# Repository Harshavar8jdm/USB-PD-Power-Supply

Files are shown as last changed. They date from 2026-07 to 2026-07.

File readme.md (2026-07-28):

# CH224A USB Power Delivery (PD) Trigger Board

A 4-layer custom printed circuit board designed around the WCH CH224A USB Power Delivery sink controller. This board requests discrete voltage profiles from 5V up to 28V (USB PD 3.0 / 3.1 EPR) at power levels up to 100W, making standard USB-C PD power supplies usable for bench instruments, prototypes, and DC-powered devices.

---

## Board Visuals

### 3D Renders
| Top View | Bottom View |
| :---: | :---: |
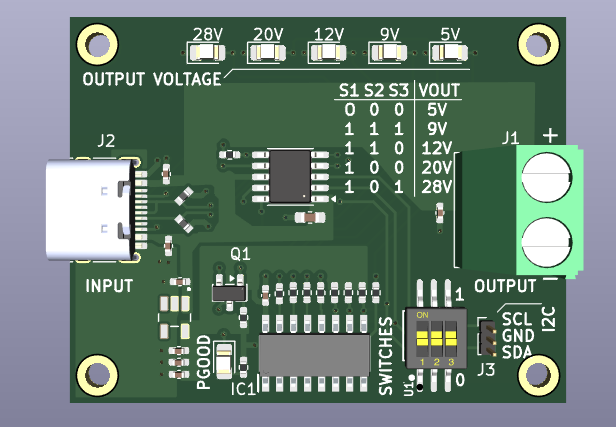
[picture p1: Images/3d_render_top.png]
3D Render Top
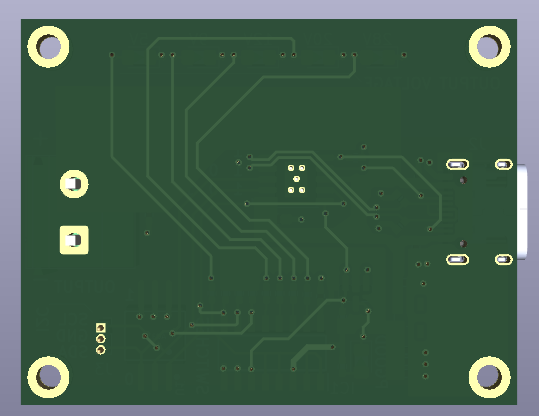
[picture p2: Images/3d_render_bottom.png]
3D Render Bottom
|  |  |

---

## Features

* **Wide Voltage Range:** Requests 5V, 9V, 12V, 20V, or 28V output based on switch configuration or digital override.
* **Dual Control Modes:** Manual hardware selection via a 3-position DIP switch, or digital register control over an onboard I2C header.
* **Visual Status Indicators:** Dedicated surface-mount LEDs for each voltage profile (5V, 9V, 12V, 20V, 28V).
* **High-Current Power Path:** Solid copper pours on VBUS and GND pads of the 16-pin USB-C receptacle to reduce resistance and thermal rise under 5A loads.
* **4-Layer PCB Layout:** Dedicated internal ground planes (Layer 2 & Layer 3) provide return paths and heat spreading.
* **Silkscreen Truth Table:** Printed reference table on top silk for direct voltage-setting configuration without consulting external documentation.
* **Output Termination:** 2-pin Phoenix screw terminal block for connection to external loads.

---

## Specifications

| Parameter | Specification |
| :--- | :--- |
| **Input Connector** | 16-Pin USB Type-C Receptacle (`J2`) |
| **Output Connector** | 2-Pin Screw Terminal Block (`J1`) |
| **Controller IC** | WCH CH224A |
| **Supported Voltages** | 5V, 9V, 12V, 20V, 28V (EPR) |
| **Maximum Current** | Up to 5A |
| **Maximum Power** | 100W |
| **Control Interface** | 3-position DIP Switch (`S1`, `S2`, `S3`) & 3-pin I2C Header (`J3`) |
| **Stackup** | 4-layer (Signal / GND / GND / Signal) |

---

## Voltage Selection (DIP Switch Truth Table)

The DIP switch (`S1`, `S2`, `S3`) controls the configuration pins of the CH224A. Use the following logic combinations to select the target output voltage:

| S1 | S2 | S3 | Selected Output Voltage (VOUT) |
| :---: | :---: | :---: | :---: |
| `0` | `0` | `0` | **5V** |
| `1` | `1` | `1` | **9V** |
| `1` | `1` | `0` | **12V** |
| `1` | `0` | `0` | **20V** |
| `1` | `0` | `1` | **28V** |

> **Note:** The truth table is also silkscreened on the top layer of the PCB for quick reference.

---

## PCB Layout & Schematic

### Schematic Diagram
* [View Schematic (PDF)](Images/schematic.pdf)

### Layer Stackup & Routing
| Layer | Layout Image | Description |
| :--- | :---: | :--- |
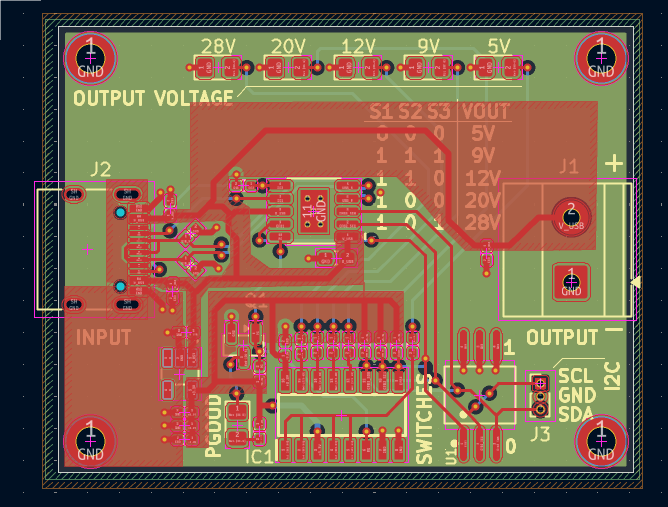
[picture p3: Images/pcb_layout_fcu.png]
Top Layer
| **Top Layer (F.Cu)** |  | Signal routing, component placement, voltage LEDs, and `V_USB` power pours. |
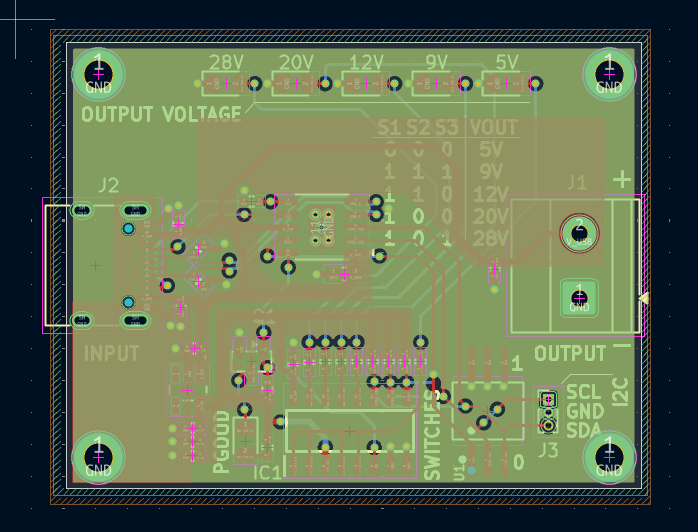
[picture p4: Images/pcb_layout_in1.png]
Inner Layer 1
| **Inner Layer 1 (In1.Cu)** |  | Continuous Ground Plane (GND). |
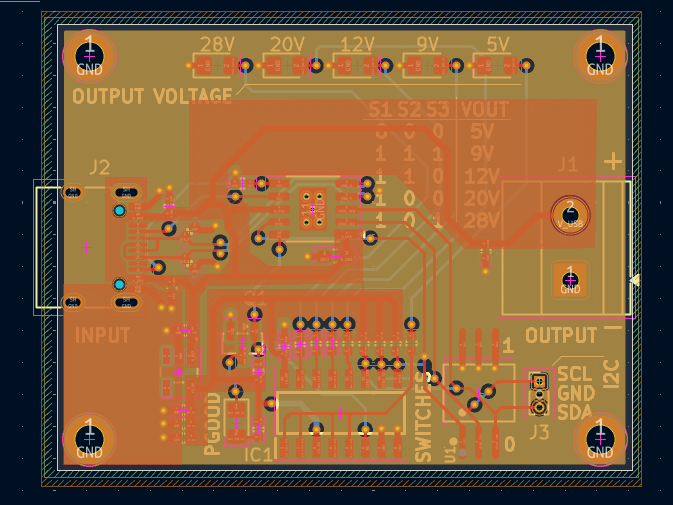
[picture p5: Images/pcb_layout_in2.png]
Inner Layer 2
| **Inner Layer 2 (In2.Cu)** |  | Continuous Ground Plane (GND). |
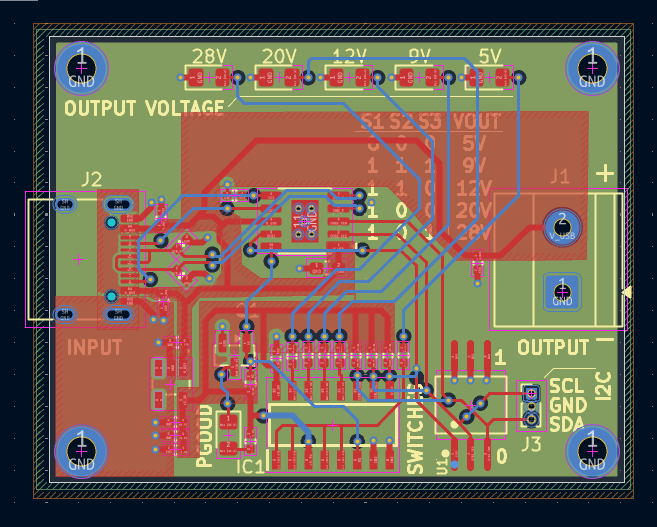
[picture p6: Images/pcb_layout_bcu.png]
Bottom Layer
| **Bottom Layer (B.Cu)** |  | Low-speed signal routing and DIP switch interconnects. |

---

## Hardware Architecture

### High-Current Design Considerations
* **Solid Copper Pours:** VBUS and GND pads on the USB-C receptacle avoid thermal relief necking to maximize current delivery up to 5A without excessive trace heating.
* **Thermal Management:** Dual internal ground planes serve as an integrated thermal heat spreader for the CH224A IC and power paths.

### Microcontroller Interface (I2C Header - J3)
The `J3` header exposes the I2C bus pins (`SCL`, `GND`, `SDA`) connected to the CH224A controller, allowing an external host MCU (e.g., STM32, ESP32, AVR) to read status registers or programmatically switch profiles.

* **Pinout:**
  1. `SCL` (I2C Clock)
  2. `GND` (Ground)
  3. `SDA` (I2C Data)
* **Bus Pull-ups:** The board omits dedicated pull-up resistors on SDA/SCL to minimize component count. Activate the internal pull-up resistors on the host microcontroller's GPIO pins when using this interface.

---

## Repository File Structure

```text
├── Images/
│   ├── 3d_render_top.png
│   ├── 3d_render_bottom.png
│   ├── pcb_layout_fcu.png
│   ├── pcb_layout_in1.png
│   ├── pcb_layout_in2.png
│   ├── pcb_layout_bcu.png
│   └── schematic.pdf
└── README.md

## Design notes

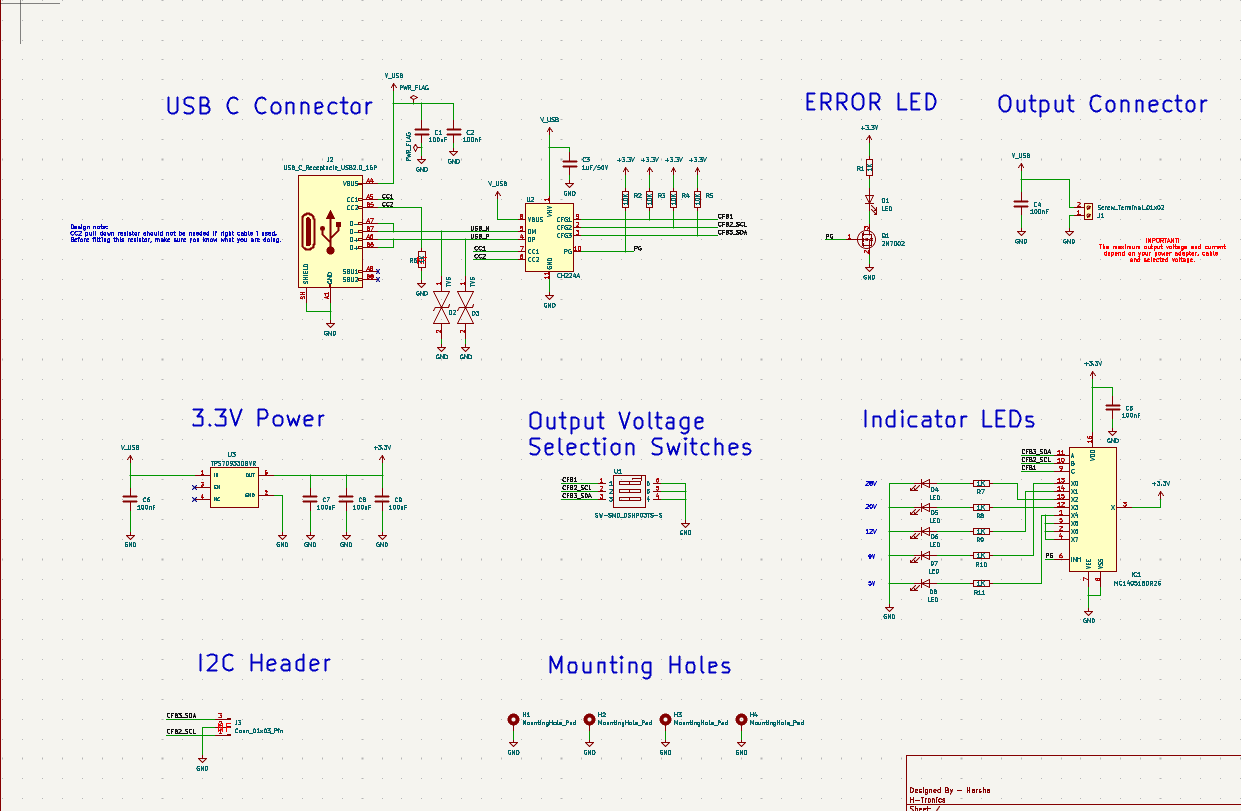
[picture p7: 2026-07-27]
Images/schematic.png

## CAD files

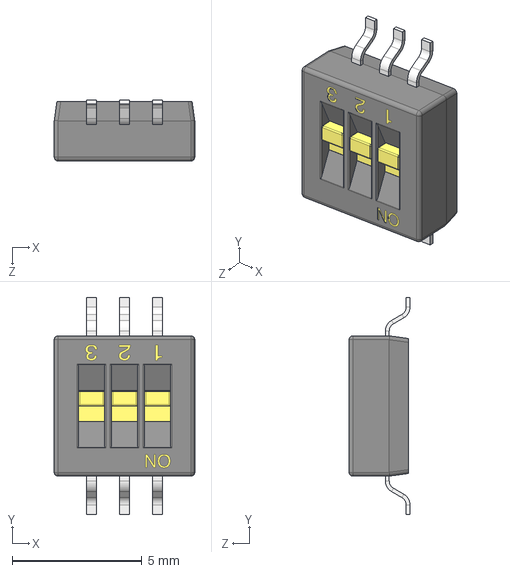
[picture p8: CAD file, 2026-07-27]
ext-libs/SW-SMD_DSHP03TS-S_DSHP03TS-S_C319051/SW-SMD_DSHP03TS-S_DSHP03TS-S_C319051.step
5.41 x 8.35 x 2.35 mm

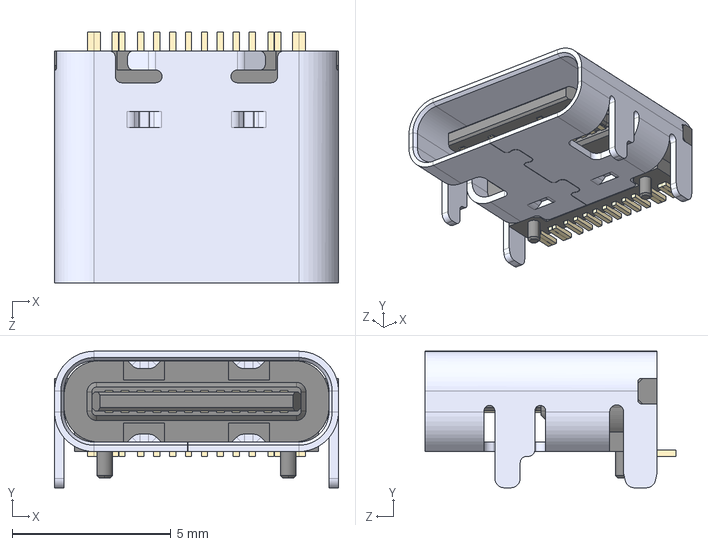
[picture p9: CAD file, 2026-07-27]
ext-libs/TYPE-C-31-M-12--3DModel-STEP-56544.STEP
8.94 x 4.30 x 7.90 mm

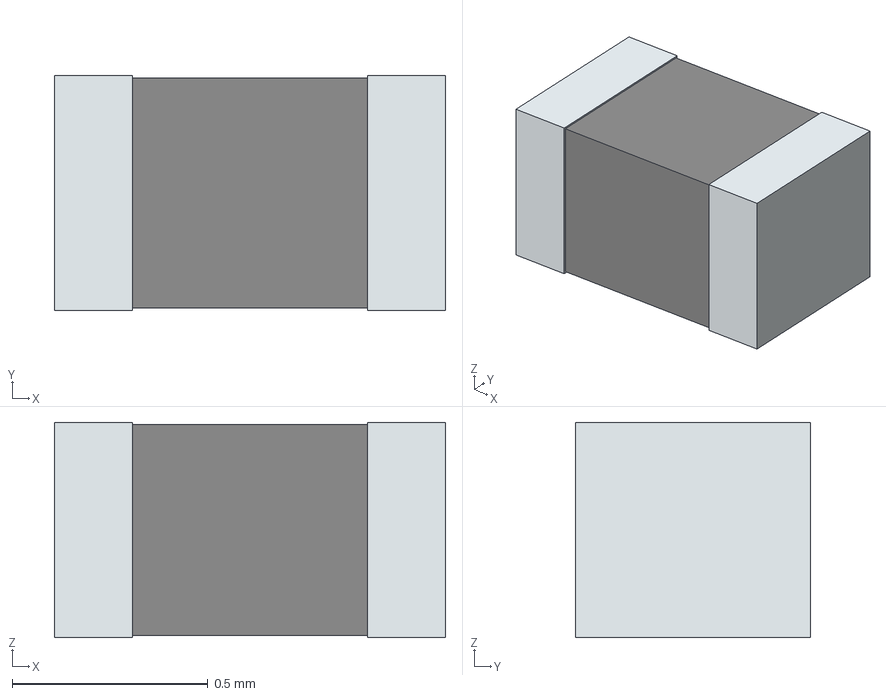
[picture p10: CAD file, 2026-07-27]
ext-libs/GG0402052R542P/3D/GG0402052R542P.stp
1.00 x 0.6 x 0.55 mm
term1
term2

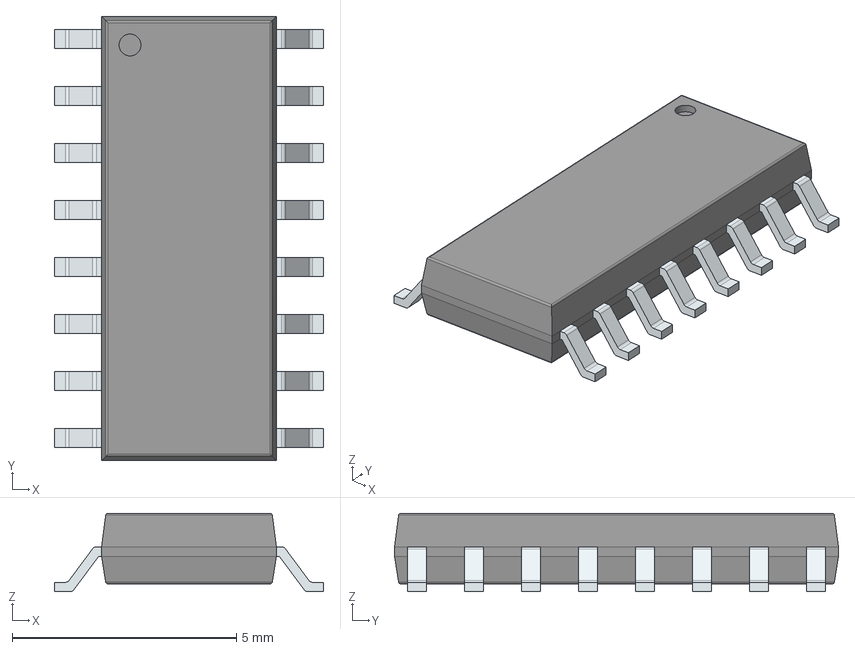
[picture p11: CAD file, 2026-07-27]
ext-libs/LIB_MC14051BDR2G/MC14051BDR2G/3D/MC14051BDR2G.stp
6.00 x 9.90 x 1.75 mm
PinsArrayLR

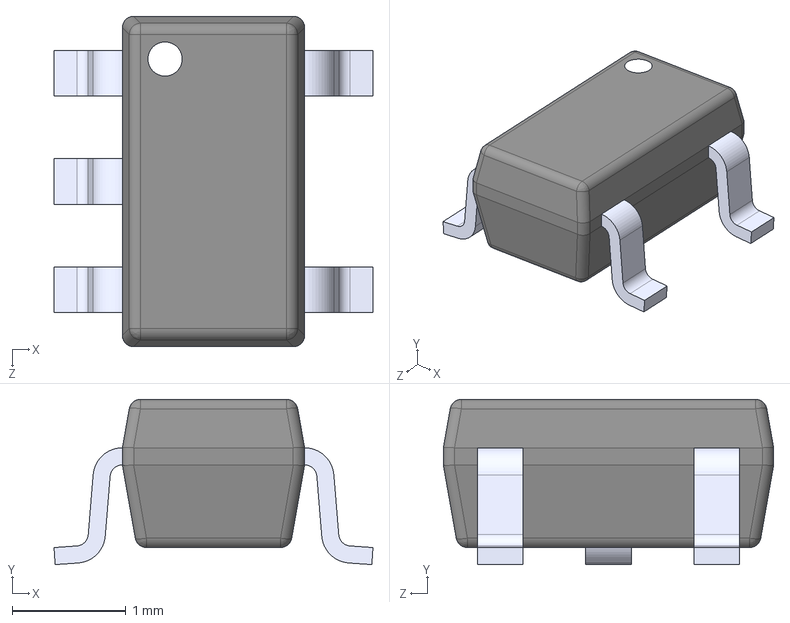
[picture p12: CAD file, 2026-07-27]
ext-libs/TPS70933DBVR/TPS70933DBVR.step
2.80 x 1.45 x 2.90 mm

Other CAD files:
ext-libs/GG0402052R542P/Allegro/dionc1006x55n.psm
ext-libs/GG0402052R542P/DEHDL/gg0402052r542p/chips/chips.prt
ext-libs/LIB_MC14051BDR2G/MC14051BDR2G/Allegro/soic127p600x175-16n.psm
ext-libs/LIB_MC14051BDR2G/MC14051BDR2G/DEHDL/mc14051bdr2g/chips/chips.prt
ext-libs/SW-SMD_DSHP03TS-S_DSHP03TS-S_C319051/SW-SMD_DSHP03TS-S_DSHP03TS-S_C319051.obj

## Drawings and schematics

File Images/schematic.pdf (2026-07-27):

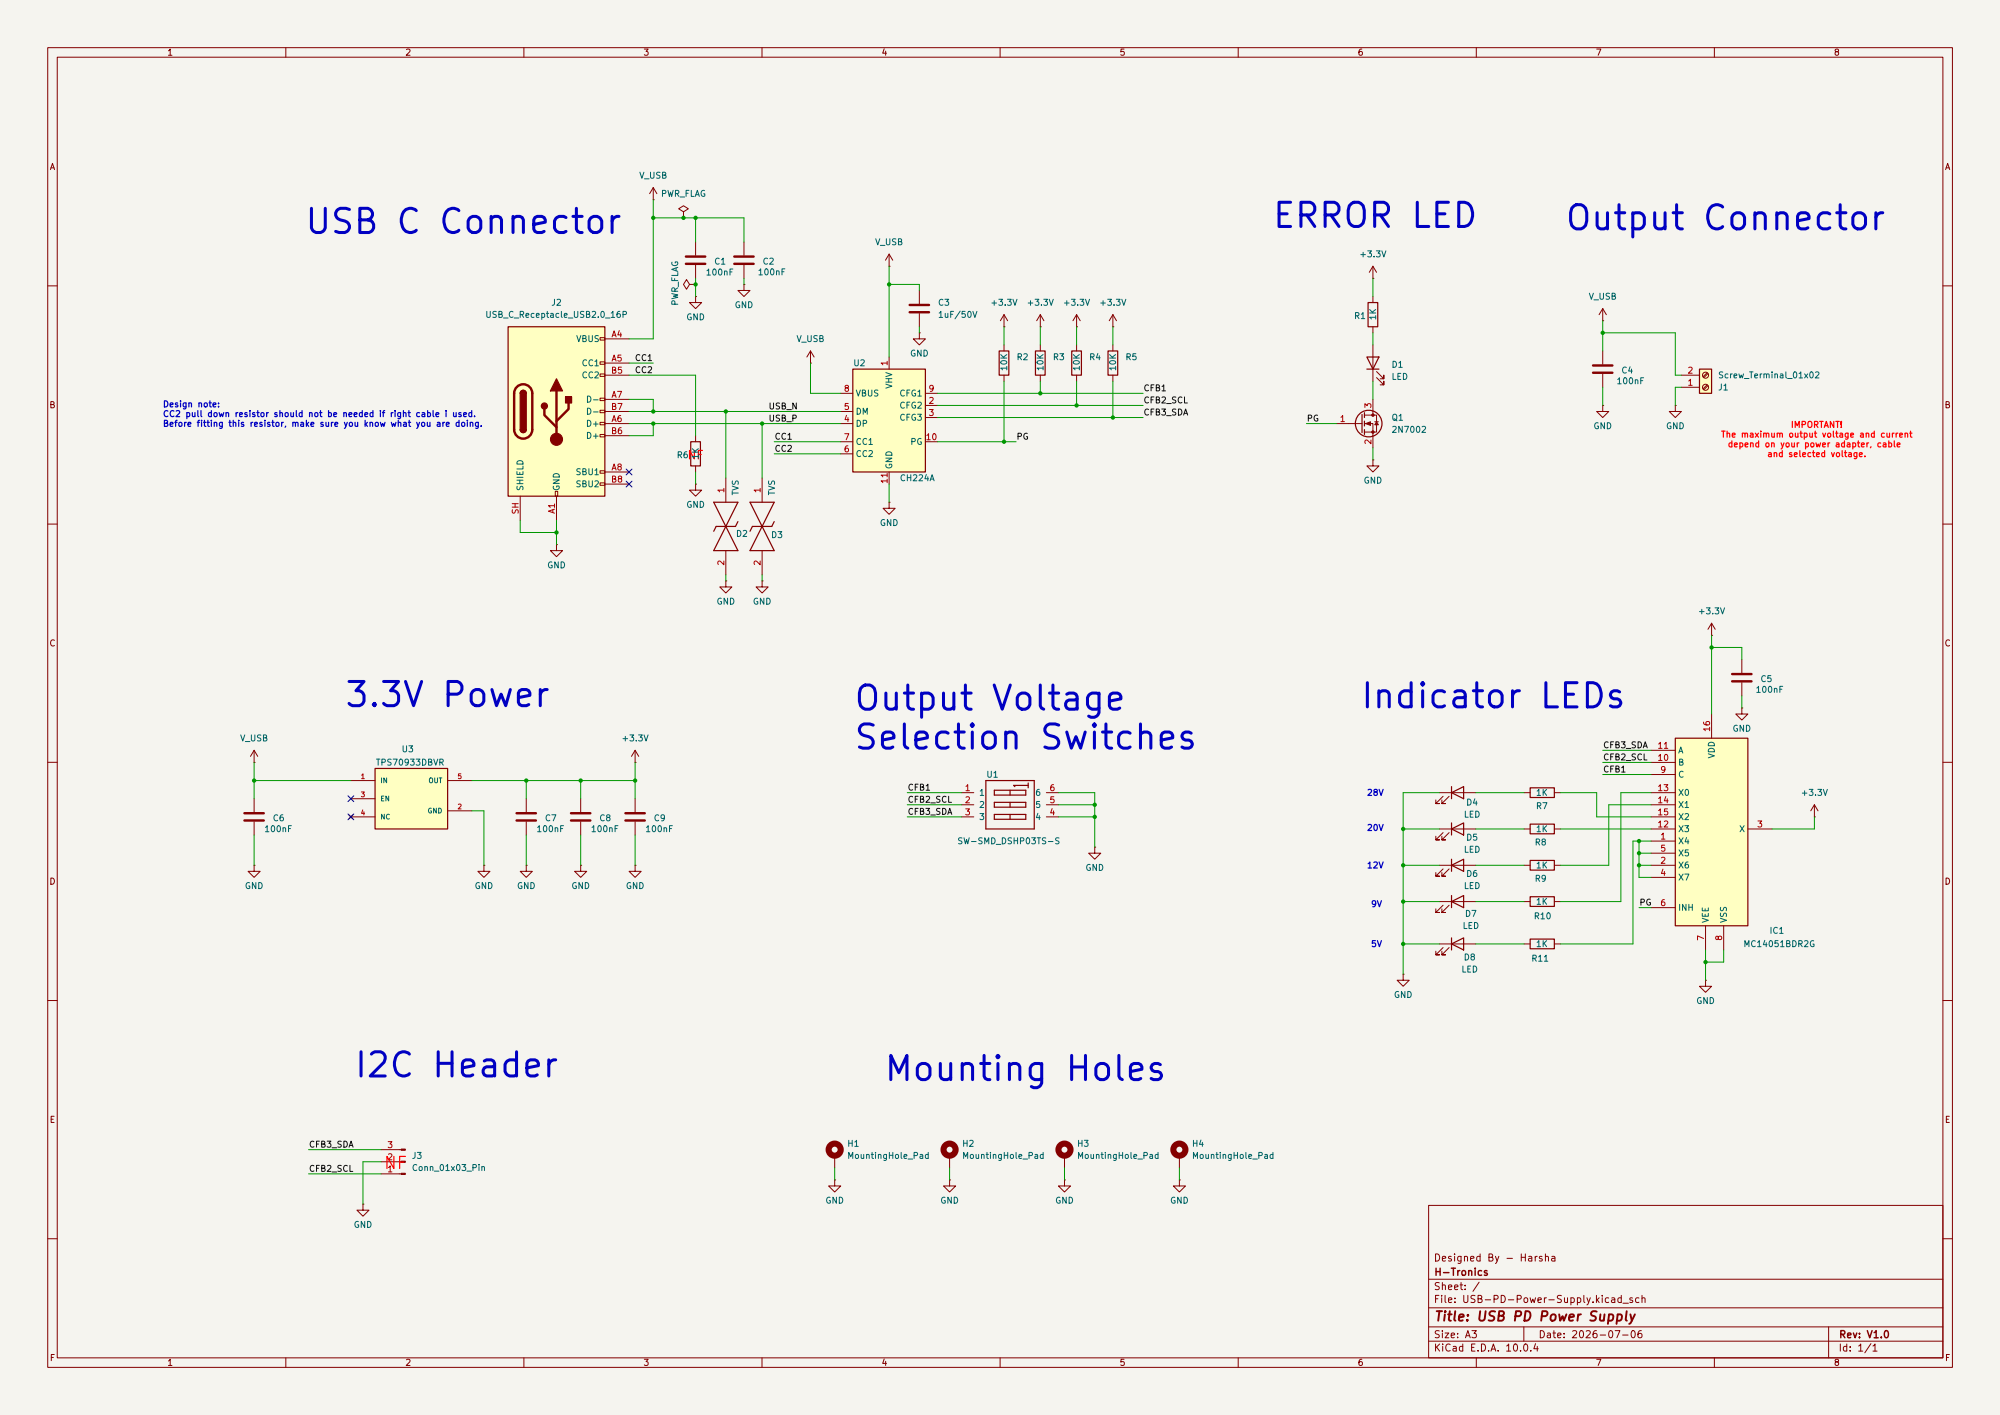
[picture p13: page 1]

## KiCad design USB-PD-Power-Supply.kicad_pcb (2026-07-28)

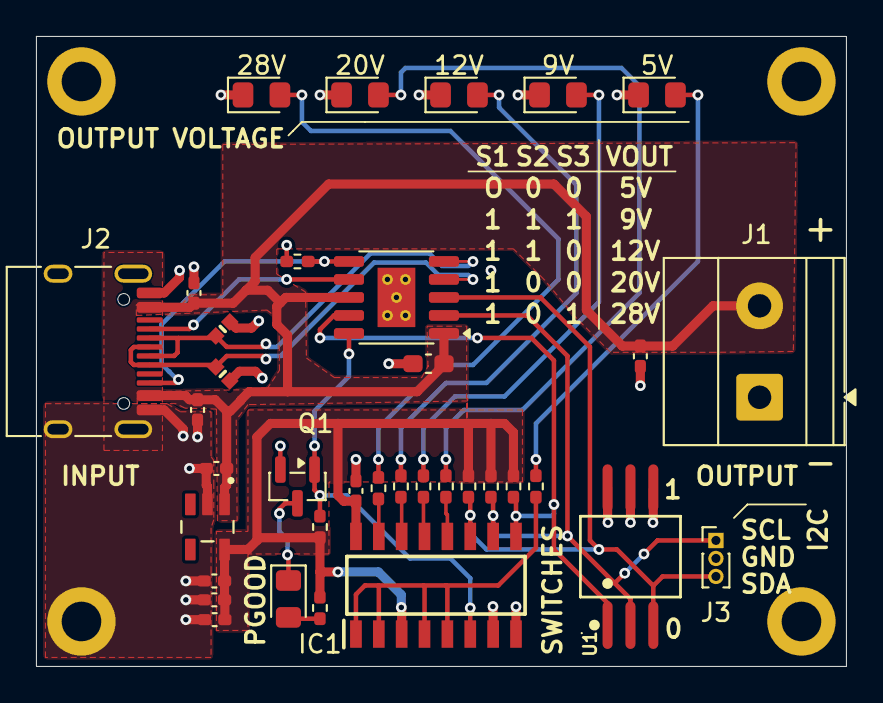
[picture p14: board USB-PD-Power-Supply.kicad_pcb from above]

Board: 4 copper layers, 45.0 x 35.0 mm, 40 parts (0 on the bottom side), 23 nets.

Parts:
5V, 9V, 12V, 20V, 28V: LED; LED_0805_2012Metric_Pad1.15x1.40mm_HandSolder
C1, C2, C4, C5, C6, C7, C8, C9: 100nF; C_0402_1005Metric_Pad0.74x0.62mm_HandSolder
C3: 1uF/50V; C_0603_1608Metric_Pad1.08x0.95mm_HandSolder
D1: LED; LED_0805_2012Metric_Pad1.15x1.40mm_HandSolder
D2, D3: TVS; DIONC1006X55N
H1, H2, H3, H4: MountingHole_Pad; MountingHole_2.2mm_M2_DIN965_Pad
IC1: MC14051BDR2G; SOIC127P600X175-16N
J1: Screw_Terminal_01x02; TerminalBlock_Phoenix_MKDS-1,5-2-5.08_1x02_P5.08mm_Horizont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
J2: USB_C_Receptacle_USB2.0_16P; USB_C_Receptacle_HRO_TYPE-C-31-M-12
J3: Conn_01x03_Pin; PinHeader_1x03_P1.00mm_Vertical
Q1: 2N7002; SOT-23
R1, R6, R7, R8, R9, R10, R11: 1K; R_0402_1005Metric_Pad0.72x0.64mm_HandSolder
R2, R3, R4, R5: 10K; R_0402_1005Metric_Pad0.72x0.64mm_HandSolder
U1: SW-SMD_DSHP03TS-S; SW-SMD_DSHP03TS-S_DSHP03TS-S_C319051
U2: CH224A; SSOP-10-1EP_3.9x4.9mm_P1mm_EP2.1x3.3mm
U3: TPS70933DBVR; SOT95P280X145-5N

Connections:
+3.3V: C5.1, C7.1, C8.1, C9.1, IC1.3 (X), IC1.16 (VDD), R1.1, R2.1, R3.1, R4.1, R5.1, U3.5 (OUT)
/CC1: J2.A5 (CC1), U2.7 (CC1)
/CC2: J2.B5 (CC2), R6.1, U2.6 (CC2)
/CFB1: IC1.9 (C), R3.2, U1.1, U2.9 (CFG1)
/CFB2_SCL: IC1.10 (B), J3.1, R4.2, U1.2, U2.2 (CFG2)
/CFB3_SDA: IC1.11 (A), J3.3, R5.2, U1.3, U2.3 (CFG3)
/PG: IC1.6 (INH), Q1.1 (G), R2.2, U2.10 (PG)
/USB_N: D2.1, J2.A7 (D-), J2.B7 (D-), U2.5 (DM)
/USB_P: D3.1, J2.A6 (D+), J2.B6 (D+), U2.4 (DP)
GND: 5V.1 (K), 9V.1 (K), 12V.1 (K), 20V.1 (K), 28V.1 (K), C1.2, C2.2, C3.1, C4.2, C5.2, C6.2, C7.2, C8.2, C9.2, D2.2, D3.2, H1.1 (1_1), H2.1 (1_1), H3.1 (1_1), H4.1 (1_1), IC1.7 (VEE), IC1.8 (VSS), J1.1, J2.A1 (GND), J2.A12 (GND), J2.B1 (GND), J2.B12 (GND), J2.SH (SHIELD), J3.2, Q1.2 (S), R6.2, U1.4, U1.5, U1.6, U2.11 (GND), U2.12, U3.2 (GND)
unnamed: D1.2 (A), R1.2
unnamed: D1.1 (K), Q1.3 (D)
unnamed: 28V.2 (A), R7.1
unnamed: 20V.2 (A), R8.1
unnamed: 12V.2 (A), R9.1
unnamed: 9V.2 (A), R10.1
unnamed: 5V.2 (A), R11.1
unnamed: IC1.13 (X0), R10.2
unnamed: IC1.14 (X1), R9.2
unnamed: IC1.15 (X2), R7.2
unnamed: IC1.12 (X3), R8.2
unnamed: IC1.1 (X4), IC1.2 (X6), IC1.4 (X7), IC1.5 (X5), R11.2
V_USB: C1.1, C2.1, C3.2, C4.1, C6.1, J1.2, J2.A4 (VBUS), J2.A9 (VBUS), J2.B4 (VBUS), J2.B9 (VBUS), U2.1 (VHV), U2.8 (VBUS), U3.1 (IN)

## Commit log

2026-07-27 Schematic and Ext-libs
    [DIONC1006X55N.PcbLib, EDI2CAP.CFG, GG0402052R542P.SchLib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]
2026-07-27 Completed Routing, Adjusted Silkscreen, and Images
    [TYPE-C-31-M-12--3DModel-STEP-56544.STEP, USB-PD-Power-Supply.kicad_pcb, USB-PD-Power-Supply.kicad_sch]
2026-07-28 generated gerber files
    [USB-PD-Power-Supply-B_Cu.gbr, USB-PD-Power-Supply-B_Mask.gbr, USB-PD-Power-Supply-B_Paste.gbr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]
